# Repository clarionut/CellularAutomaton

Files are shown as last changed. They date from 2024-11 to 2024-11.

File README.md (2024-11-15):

# Cellular Automaton

This repository contains details of an Arduino-based emulation of the [NonlinearCircuits Cellular Automata](https://www.nonlinearcircuits.com/modules/p/cellular-automata) synthesiser module but with additional functionality.

CellularAutomaton

The original is a tour-de-force of 4xxx CMOS circuit design, but a microcontroller-based implementation is much simpler to design and assemble, probably cheaper and, most importantly, offers the possibility for interesting additional functionality. In particular, this implemetation allows a probabilistic approach to the cellular automaton rules and can run using its own internal clock.

The rules (more details in the Arduino code) determine if each cell will be OFF or allowed to be ON in the next generation. An OFF cell will definitely be OFF but an 'allowed' cell may be ON or OFF depending on a voltage controlled Survival probability. VC inputs of 5V (or above) will set the Survival pobability to 1 (and the cell will definitely be ON) while inputs of 0V (or below) give a survival probability nearer to 0 (and the cell will probably be OFF). Intermediate values give an increasing probability of survival as the control voltage increases. This has the effect of varying the density of ON cells in the grid and increasing the randomness of the grid patterns. The individual Seed cell inputs also accept analogue (0 - 5V) control voltages rather than simple gates allowing probabilistic seeding of the grid. There is also a global Seed probability control which can be set manually or by an external control voltage allowing the Cellular Automaton to be run without requiring direct inputs to the individual seed cells. The Seed probability inputs assign a probability of 0 for inputs of 0V or below, so the cellular automaton can be blanked.

In addition the module can run using an external clock or an internal clock with exponential voltage control. The clock mode is selected by a switch and the same input is used for both the external clock and voltage control of the internal clock.

Outputs are very similar to the Nonlinear Circuits original - a grid of 16 gate outputs (6V output in this case) which are high when the corresponding cell in the grid is ON and three pseudo-random CV outputs, one controlled by the top eight cells of the grid, one by the bottom eight cells and one by all cells combined.

## Hardware notes

The Arduino sketch requires 7 analogue inputs so I used a 16MHz Arduino Pro Mini board mounted on the PCB rather than an ATmega328P (only 6 analogue inputs) mounted directly on the board. This drives two CD4094B shift registers running on 6V which in turn drive the LED matrix and gate outputs. The 6V supply provides a normalled voltage to the probability and clock inputs via 10k resistors mounted on the input sockets; with the 50k input level potentiometers this provides 0 - 5V for each of the inputs in the absence of an external connection. Inputs are protected against out-of-range voltages. The LED matrix in the original is 3D printed and uses 16 green 3mm ultrabright LEDs. The STL files are on [Thingiverse](https://www.thingiverse.com/thing:6831147).

## KiCad files

The schematic and PCB files are provided in KiCad 7 format and as PDFs. Note that the front copper ground plane is excluded from the PDF for clarity but is present in the KiCad files. The schematic uses some custom symbols and the PCB some custom footprints, so you will need to download my [custom KiCad libraries](https://github.com/clarionut/kiCad_libraries) and tell KiCad where to find them. Note that Arduino Pro Minis don't all have the same footprint, so you may have to further customise the PCB. The PCB file is intended to be processed by the KiCad 'Round Tracks' plugin but will work perfectly well without. I've included the Gerber files but these will only be useful if you mount the PCB on brackets behind and perpendicular to the front panel.

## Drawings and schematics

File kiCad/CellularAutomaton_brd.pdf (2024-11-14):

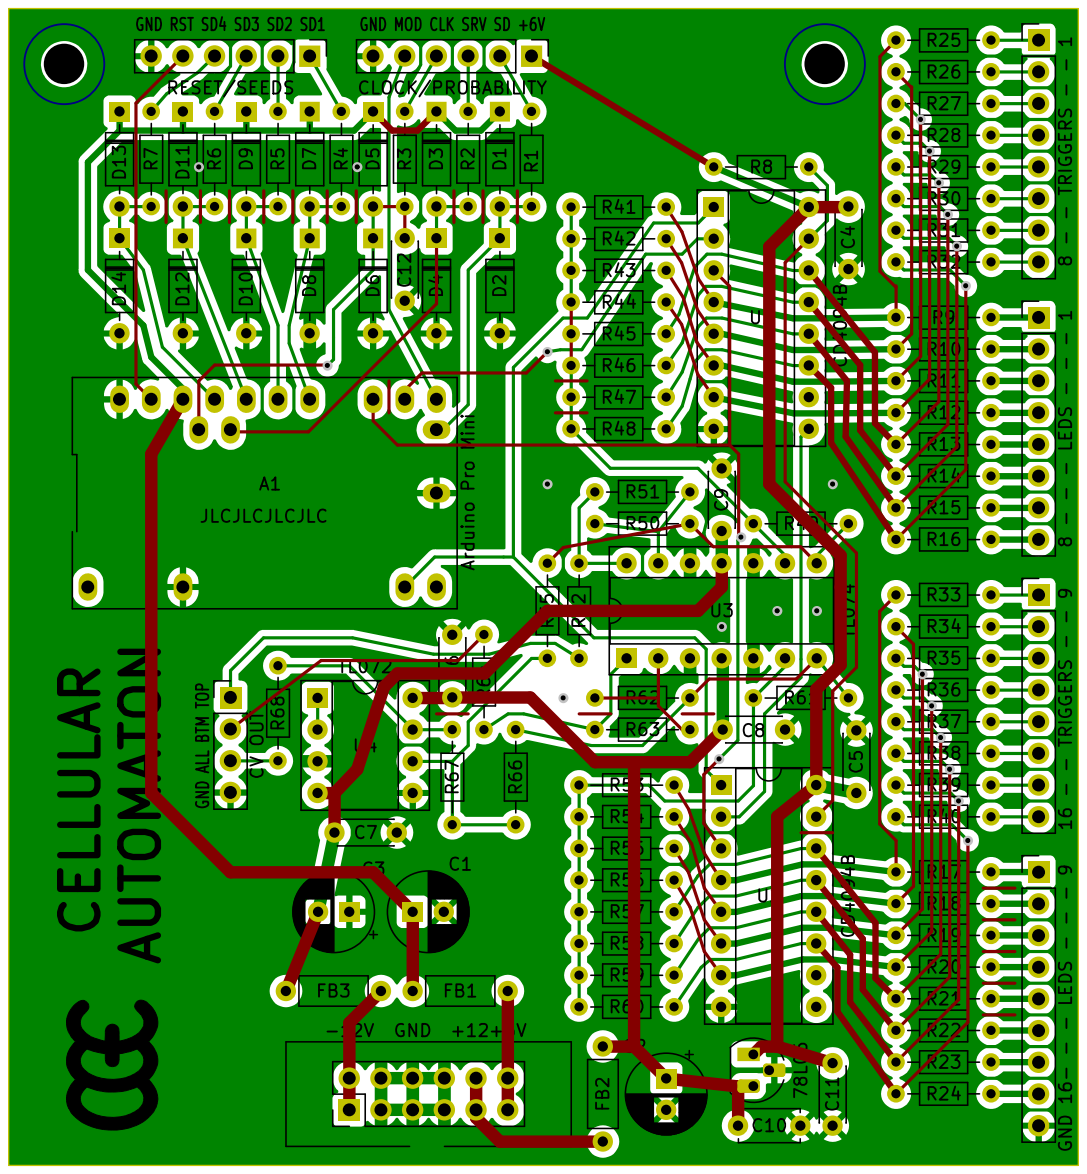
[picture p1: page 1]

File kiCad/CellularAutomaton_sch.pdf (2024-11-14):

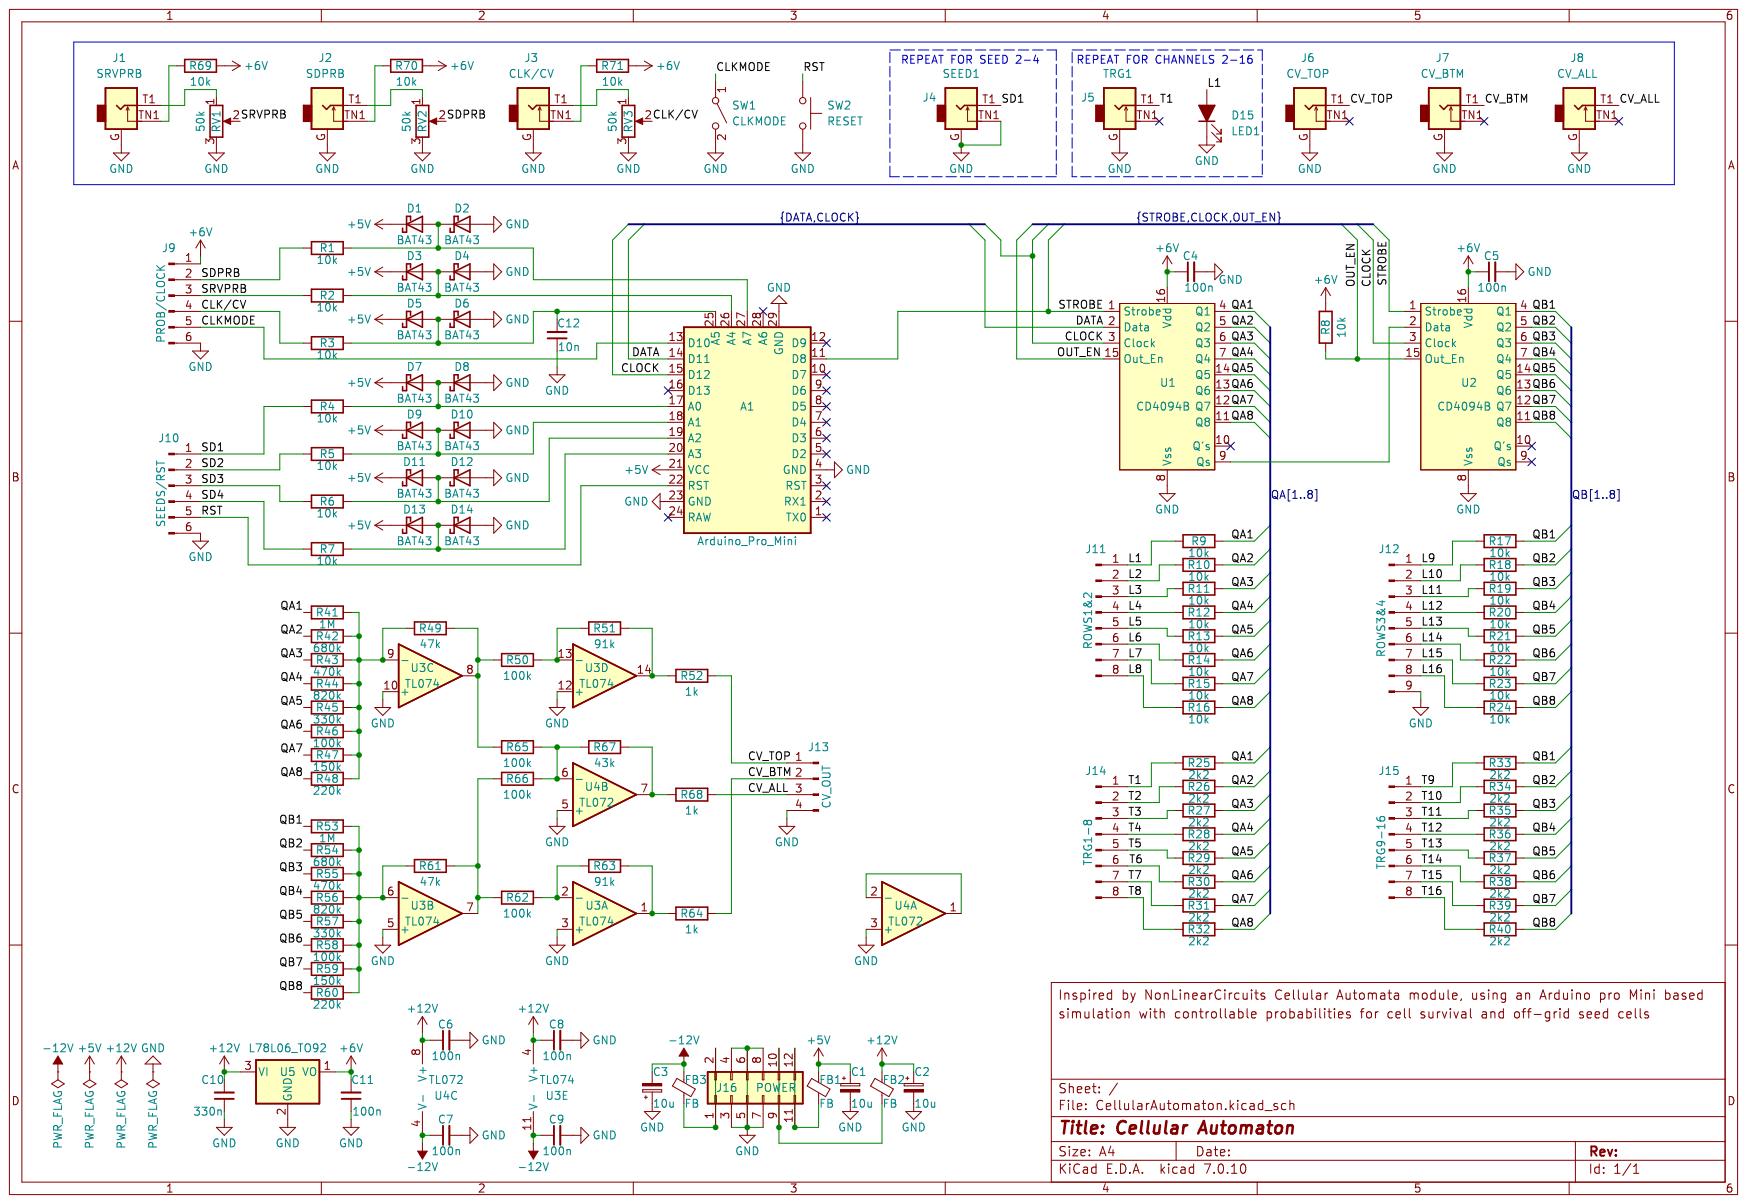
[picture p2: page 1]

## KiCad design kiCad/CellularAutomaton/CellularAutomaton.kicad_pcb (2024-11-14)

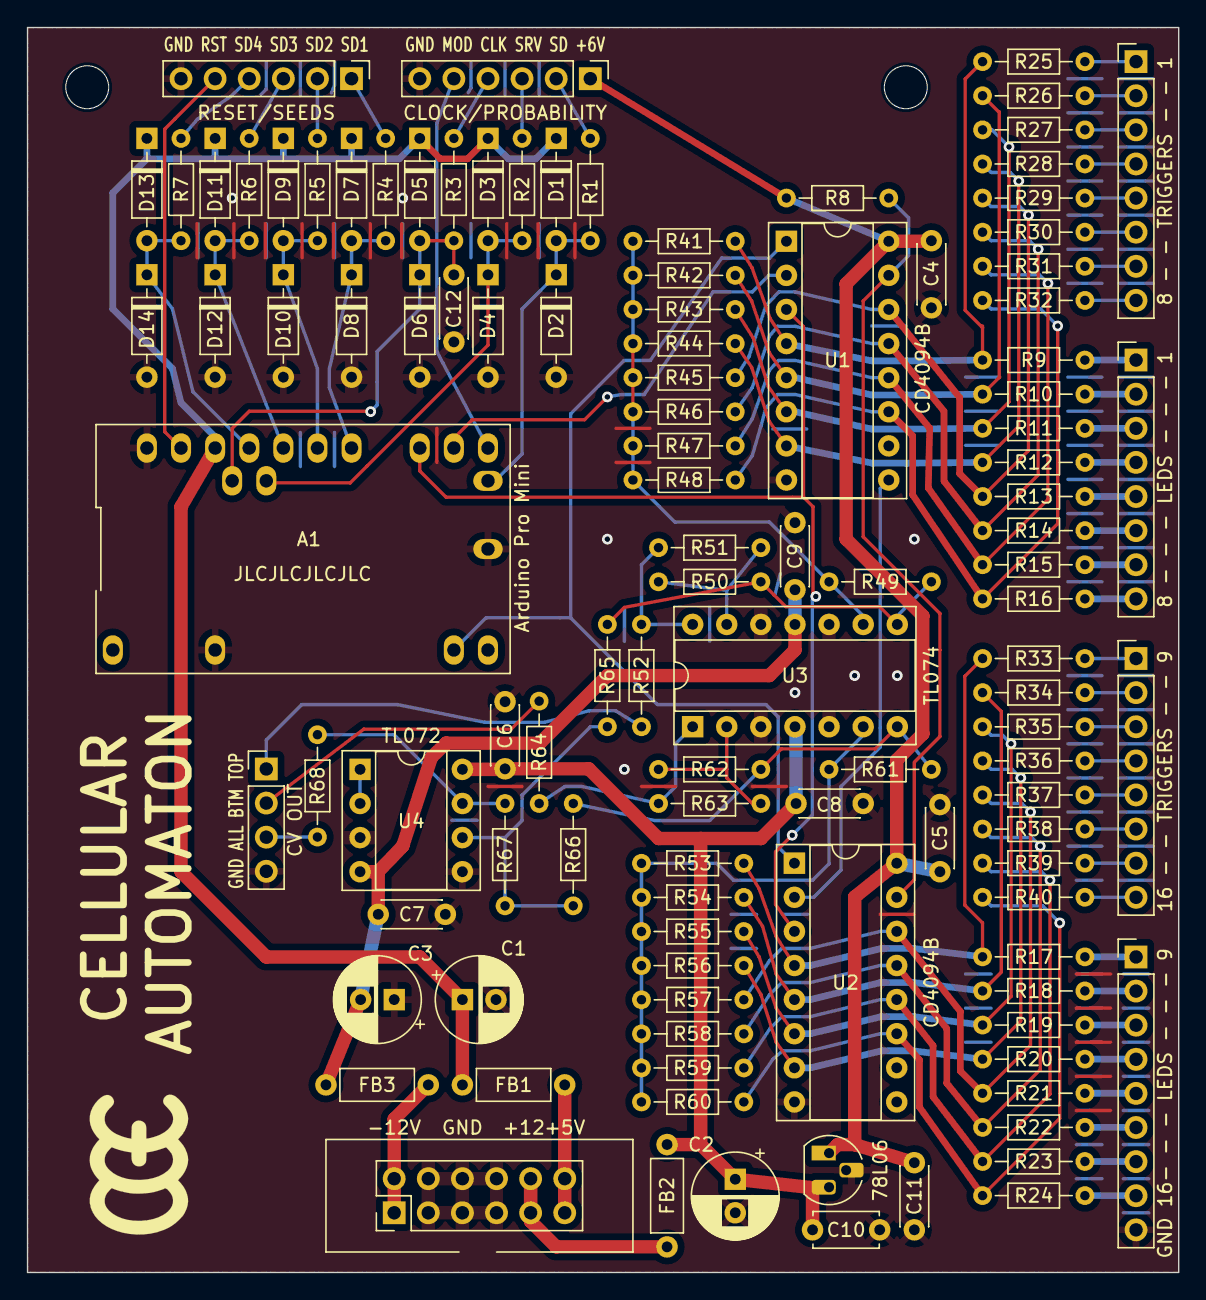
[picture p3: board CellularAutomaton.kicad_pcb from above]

Board: 2 copper layers, 85.7 x 92.7 mm, 111 parts (0 on the bottom side), 91 nets.

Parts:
A1: Arduino_Pro_Mini
C1, C2, C3: 10u; CP_Radial_D6.3mm_P2.50mm
C4, C5, C6, C7, C8, C9, C11: 100n; C_Disc_D4.3mm_W1.9mm_P5.00mm
C10: 330n; C_Disc_D4.7mm_W2.5mm_P5.00mm
C12: 10n; C_Disc_D4.3mm_W1.9mm_P5.00mm
D1, D2, D3, D4, D5, D6, D7, D8, D9, D10, D11, D12, D13, D14: BAT43; D_DO-35_SOD27_P7.62mm_Horizontal
FB1, FB2, FB3: FB; L_Axial_L5.3mm_D2.2mm_P7.62mm_Horizontal_Vishay_IM-1
J9: PROB/CLOCK; PinHeader_1x06_P2.54mm_Vertical
J10: SEEDS/RST; PinHeader_1x06_P2.54mm_Vertical
J11: ROWS1&2; PinHeader_1x08_P2.54mm_Vertical
J12: ROWS3&4; PinHeader_1x09_P2.54mm_Vertical
J13: CV_OUT; PinHeader_1x04_P2.54mm_Vertical
J14: TRG1-8; PinHeader_1x08_P2.54mm_Vertical
J15: TRG9-16; PinHeader_1x08_P2.54mm_Vertical
J16: POWER; Power_2x06
R1, R2, R3, R4, R5, R6, R7, R8, R9, R10, R11, R12, R13, R14, R15, R16, R17, R18, R19, R20, R21, R22, R23, R24: 10k; R_Axial_DIN0204_L3.6mm_D1.6mm_P7.62mm_Horizontal
R25, R26, R27, R28, R29, R30, R31, R32, R33, R34, R35, R36, R37, R38, R39, R40: 2k2; R_Axial_DIN0204_L3.6mm_D1.6mm_P7.62mm_Horizontal
R41, R53: 1M; R_Axial_DIN0204_L3.6mm_D1.6mm_P7.62mm_Horizontal
R42, R54: 680k; R_Axial_DIN0204_L3.6mm_D1.6mm_P7.62mm_Horizontal
R43, R55: 470k; R_Axial_DIN0204_L3.6mm_D1.6mm_P7.62mm_Horizontal
R44, R56: 820k; R_Axial_DIN0204_L3.6mm_D1.6mm_P7.62mm_Horizontal
R45, R57: 330k; R_Axial_DIN0204_L3.6mm_D1.6mm_P7.62mm_Horizontal
R46, R50, R58, R62, R65, R66: 100k; R_Axial_DIN0204_L3.6mm_D1.6mm_P7.62mm_Horizontal
R47, R59: 150k; R_Axial_DIN0204_L3.6mm_D1.6mm_P7.62mm_Horizontal
R48, R60: 220k; R_Axial_DIN0204_L3.6mm_D1.6mm_P7.62mm_Horizontal
R49, R61: 47k; R_Axial_DIN0204_L3.6mm_D1.6mm_P7.62mm_Horizontal
R51, R63: 91k; R_Axial_DIN0204_L3.6mm_D1.6mm_P7.62mm_Horizontal
R52, R64, R68: 1k; R_Axial_DIN0204_L3.6mm_D1.6mm_P7.62mm_Horizontal
R67: 43k; R_Axial_DIN0204_L3.6mm_D1.6mm_P7.62mm_Horizontal
U1, U2: CD4094B; DIP-16_W7.62mm_Socket
U3: TL074; DIP-14_W7.62mm_Socket
U4: TL072; DIP-8_W7.62mm_Socket
U5: L78L06_TO92; TO-92_HandSolder

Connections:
+5V: A1.21 (VCC), C1.1, D1.1 (K), D3.1 (K), D5.1 (K), D7.1 (K), D9.1 (K), D11.1 (K), D13.1 (K), FB1.1
+6V: C4.1, C5.1, C11.2, J9.1, R8.1, U1.16 (Vdd), U2.16 (Vdd), U5.1 (VO)
+12V: C2.1, C6.1, C8.1, C10.2, FB2.1, U3.4 (V+), U4.8 (V+), U5.3 (VI)
-12V: C3.2, C7.1, C9.1, FB3.1, U3.11 (V-), U4.4 (V-)
/CLKMODE: A1.13 (D10), J9.5
/CLK/CV: J9.4, R3.1
/CLOCK: A1.15 (D12), U1.3 (Clock), U2.3 (Clock)
/CV_ALL: J13.3, R68.2
/CV_BTM: J13.2, R64.2
/CV_TOP: J13.1, R52.2
/DATA: A1.14 (D11), U1.2 (Data)
/L1: J11.1, R9.2
/L2: J11.2, R10.2
/L3: J11.3, R11.2
/L4: J11.4, R12.2
/L5: J11.5, R13.2
/L6: J11.6, R14.2
/L7: J11.7, R15.2
/L8: J11.8, R16.2
/L9: J12.1, R17.2
/L10: J12.2, R18.2
/L11: J12.3, R19.2
/L12: J12.4, R20.2
/L13: J12.5, R21.2
/L14: J12.6, R22.2
/L15: J12.7, R23.2
/L16: J12.8, R24.2
/OUT_EN: R8.2, U1.15 (Out_En), U2.15 (Out_En)
/QA1: R9.1, R25.1, R41.1, U1.4 (Q1)
/QA2: R10.1, R26.1, R42.1, U1.5 (Q2)
/QA3: R11.1, R27.1, R43.1, U1.6 (Q3)
/QA4: R12.1, R28.1, R44.1, U1.7 (Q4)
/QA5: R13.1, R29.1, R45.1, U1.14 (Q5)
/QA6: R14.1, R30.1, R46.1, U1.13 (Q6)
/QA7: R15.1, R31.1, R47.1, U1.12 (Q7)
/QA8: R16.1, R32.1, R48.1, U1.11 (Q8)
/QB1: R17.1, R33.1, R53.1, U2.4 (Q1)
/QB2: R18.1, R34.1, R54.1, U2.5 (Q2)
/QB3: R19.1, R35.1, R55.1, U2.6 (Q3)
/QB4: R20.1, R36.1, R56.1, U2.7 (Q4)
/QB5: R21.1, R37.1, R57.1, U2.14 (Q5)
/QB6: R22.1, R38.1, R58.1, U2.13 (Q6)
/QB7: R23.1, R39.1, R59.1, U2.12 (Q7)
/QB8: R24.1, R40.1, R60.1, U2.11 (Q8)
/RST: A1.22 (RST), J10.5
/SD1: J10.1, R4.1
/SD2: J10.2, R5.1
/SD3: J10.3, R6.1
/SD4: J10.4, R7.1
/SDPRB: J9.2, R1.1
/SRVPRB: J9.3, R2.1
/STROBE: A1.11 (D8), U1.1 (Strobe), U2.1 (Strobe)
/T1: J14.1, R25.2
/T2: J14.2, R26.2
/T3: J14.3, R27.2
/T4: J14.4, R28.2
/T5: J14.5, R29.2
/T6: J14.6, R30.2
/T7: J14.7, R31.2
/T8: J14.8, R32.2
/T9: J15.1, R33.2
/T10: J15.2, R34.2
/T11: J15.3, R35.2
/T12: J15.4, R36.2
/T13: J15.5, R37.2
/T14: J15.6, R38.2
/T15: J15.7, R39.2
/T16: J15.8, R40.2
GND: A1.4 (GND), A1.23 (GND), A1.29 (GND), C1.2, C2.2, C3.1, C4.2, C5.2, C6.2, C7.2, C8.2, C9.2, C10.1, C11.1, C12.1, D2.2 (A), D4.2 (A), D6.2 (A), D8.2 (A), D10.2 (A), D12.2 (A), D14.2 (A), J9.6, J10.6, J12.9, J13.4, J16.3, J16.4, J16.5, J16.6, J16.7, J16.8, U1.8 (Vss), U2.8 (Vss), U3.3 (+), U3.5 (+), U3.10 (+), U3.12 (+), U4.3 (+), U4.5 (+), U5.2 (GND)
unnamed: A1.17 (A0), D7.2 (A), D8.1 (K), R4.2
unnamed: A1.18 (A1), D9.2 (A), D10.1 (K), R5.2
unnamed: A1.19 (A2), D11.2 (A), D12.1 (K), R6.2
unnamed: A1.20 (A3), D13.2 (A), D14.1 (K), R7.2
unnamed: A1.26 (A4), D3.2 (A), D4.1 (K), R2.2
unnamed: A1.25 (A5), C12.2, D5.2 (A), D6.1 (K), R3.2
unnamed: A1.27 (A7), D1.2 (A), D2.1 (K), R1.2
unnamed: FB3.2, J16.1, J16.2
unnamed: FB2.2, J16.9, J16.10
unnamed: FB1.2, J16.11, J16.12
unnamed: R49.2, R50.1, R65.1, U3.8
unnamed: R51.2, R52.1, U3.14
unnamed: R61.2, R62.1, R66.1, U3.7
unnamed: R63.2, R64.1, U3.1
unnamed: R67.2, R68.1, U4.7
unnamed: U1.9 (Qs), U2.2 (Data)
unnamed: R62.2, R63.1, U3.2 (-)
unnamed: R53.2, R54.2, R55.2, R56.2, R57.2, R58.2, R59.2, R60.2, R61.1, U3.6 (-)
unnamed: R41.2, R42.2, R43.2, R44.2, R45.2, R46.2, R47.2, R48.2, R49.1, U3.9 (-)
unnamed: R50.2, R51.1, U3.13 (-)
unnamed: U4.1, U4.2 (-)
unnamed: R65.2, R66.2, R67.1, U4.6 (-)

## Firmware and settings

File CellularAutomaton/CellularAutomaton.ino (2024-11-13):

/*
    Cellular Automaton

    Program to run an Arduino-based Cellular Automaton simulation of the 
    NonlinearCircuits Cellular Automata Eurorack module. The original is
    a tour-de-force of 4xxx CMOS circuit design, but a microcontroller-
    based implementation is much simpler to design and assemble, probably
    cheaper, and also offers the possibility for additional functionality.

    This implementation has a voltage control for the probability of a
    cell being ON in each generation. This can be varied from 100% (the
    active cells are controlled entirely by the rules of the cellular
    automaton) to about 55% (the density of ON cells is generally lower
    and there are longer periods of inactivity). In addition, the seed
    cells (see below) can be activated with an adjustable random
    probability or by CV. In contrast to the original, the seed CVs
    affect the probability of the seed cells being ON rather than being
    a simple switch.

    The same rules as the original are implemented in the simulation. All
    cells except the corners use rule 150 (the cell itself and its
    orthogonal neighbours are all included in the XOR function) while the
    corner cells use rule 90 (only the orthogonal neighbours are counted).
    Each of the corner cells has a hidden off-grid seed cell neighbour
    which can be activated by an external CV.
    
    The rules are based on an extended multi-input XOR function - this is
    possible because the basic 2-input XOR function is associative. In
    practice this means that the output will be ON if the number of ON
    inputs is ODD, and OFF if the number of ON inputs is EVEN. In the
    simulation, if the cell count under the appropriate rule is ODD the
    cell will be ON in the next generation (or will have the possibility
    of being ON if the probability is < 100%).

    Control inputs for synth module:
    - four analogue inputs for seed cells, voltages set probability of
      the cell being on
    - pot for manual probability control of seed cells
    - CV input for probability of cell survival normalled to 5V
    - pot for survival CV level
    - external clock input, doubling as CV input for internal clock
    - switch for external/internal clock
    - pot for internal clock speed (CV level input, normalled to 5V)

    Outputs:
    - 16 gates, one for each cell
    - 3 CVs, one for top half of grid, one for bottom half and one for
      the whole grid (voltage levels as in the NLC original)

    C G Earnshaw 08 08 2024
*/

#define SRSTROBE 8
#define SRDATA 11
#define SRCLOCK 12
#define CLKMODE 10

uint8_t cell[6][6] = {0};
uint8_t next[6][6] = {0};
int16_t seed[4];
int16_t seedProb;
uint8_t lastClock = 0;
unsigned long genMillis = 0L;

void setup() {
  // put your setup code here, to run once:
  pinMode(SRSTROBE, OUTPUT);
  pinMode(SRCLOCK, OUTPUT);
  pinMode(SRDATA, OUTPUT);
  pinMode(CLKMODE, INPUT_PULLUP);
  randomSeed(analogRead(A6));
  //Serial.begin(115200);
}

void loop() {
  if (digitalRead(CLKMODE)) {
    // HIGH = switch open = external clock
    if (digitalRead(A5) != lastClock) {
      // Clock has changed...
       if (lastClock) {
        // ...and has gone low
        lastClock = 0;
      } else {
        // ...and has gone high, so update the CA
        updateCells();
        lastClock = 1;
      }
    }
  } else if ((millis() - genMillis) > exp((float) (1023 - analogRead(A5)) / 95.)) {
    // Internal clock and the CA needs updating
    genMillis = millis();
    updateCells();
  }
}

void setSeeds() {
  // Set some low-probability values in the off-grid seed cells
  analogRead(A0);
  seed[0] = analogRead(A0);
  analogRead(A0);
  seed[1] = analogRead(A1);
  analogRead(A2);
  seed[2] = analogRead(A2);
  analogRead(A3);
  seed[3] = analogRead(A3);
  analogRead(A7);
  seedProb = analogRead(A7);

  cell[1][0] = (random(1024) > 1023 - (seed[0] + seedProb)) ? 1 : 0;
  cell[1][5] = (random(1024) > 1023 - (seed[1] + seedProb)) ? 1 : 0;
  cell[4][0] = (random(1024) > 1023 - (seed[2] + seedProb)) ? 1 : 0;
  cell[4][5] = (random(1024) > 1023 - (seed[3] + seedProb)) ? 1 : 0;
}

void updateCells() {
  // Loop over the grid cells to work out which will be on in the next generation
  setSeeds();
  for (uint8_t i = 1; i < 5; i++) {
    for (uint8_t j = 1; j < 5; j++) {
      // Apply rule 90 to all cells
      uint8_t cellCount = cell[i-1][j] + cell[i+1][j] + cell[i][j-1] + cell[i][j+1];
      // Update to rule 150 for non-corner cells
      if (!(((1 == i) || (4 == i)) && ((1 == j) || (4 == j)))) {
        cellCount += cell[i][j];
      }
      // Apply survival probability to potentially ON cells
      if (cellCount & 0x01) {
        next[i][j] = (random(1750) > (1023 - analogRead(A4)) ? 1 : 0); // maximum useful ratio ~58%
      } else {
        next[i][j] = 0;
      }
    }
  }
  // Update the cells
  uint16_t cells = 0;
  for (uint8_t i = 1; i < 5; i++) {
    for (uint8_t j = 1; j < 5; j++) {
      cell[i][j] = next[i][j];
      cells <<= 1;
      cells |= cell[i][j];
    }
  }
  // Send the new generation to the gates and the display
  shiftReg(cells);
}

void shiftReg(uint16_t data) {
  //sends a 16-bit unsigned int to the 4094 shift registers
  digitalWrite(SRCLOCK, LOW);
  digitalWrite(SRSTROBE, LOW);
  shiftOut(SRDATA, SRCLOCK, LSBFIRST, data & 0x00FF);
  shiftOut(SRDATA, SRCLOCK, LSBFIRST, (data >> 8) & 0x00FF);
  digitalWrite(SRSTROBE, HIGH);
}

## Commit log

2024-11-14 Update README.md
    An Arduino-based emulation of the Nonlinear Circuits Cellular Automata synth module with additional functionality
2024-11-14 Create KiCad
